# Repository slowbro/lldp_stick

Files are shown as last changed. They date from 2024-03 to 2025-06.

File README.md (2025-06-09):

# LLDP Stick

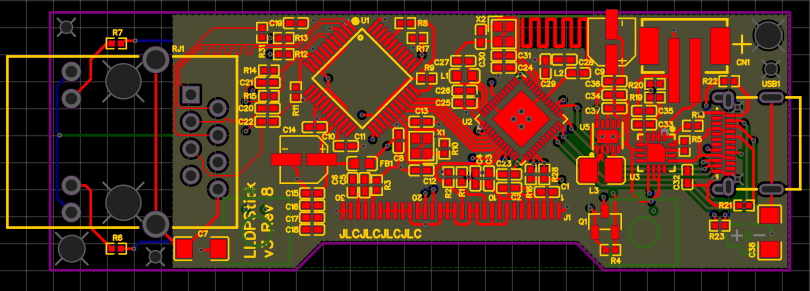
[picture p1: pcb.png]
PCB Image


## What is it?
A network diagnostic tool. Initial goal is to show LLDP information; future goal is to allow more network diagnostics over BLE with a phone app.

## Goals

- [ ] Additional diagnostics via BLE
    - [ ] Set/reset MAC Address
    - [ ] DHCP
    - [ ] Ping
- [ ] Support CDP
- [x] Reduce idle power draw (and thus improve battery life)
    - Rev 0 34mA
    - Rev 2 7mA
    - Rev 3 150uA
    - Rev 7+ 24uA!
- [ ] 1G PHY: Support switches that don't go down to 100M (i.e. Arista DCS-7280TR)
- [ ] Cost reduction: $20-$30 per stick

## Dependencies

Requires `s132_nrf52_2.0.1_softdevice.hex` to be placed in `~/.platformio/packages/framework-arduinonordicnrf5/cores/nRF5/SDK/components/softdevice/s132/hex/`. The binary can be downloaded from Nordic Semi [here](https://www.nordicsemi.com/Products/Development-software/nRF5-SDK/Download) under '11.0.0nRF5 SDK'.

## Building

1. Install [PlatformIO](https://platformio.org/).
2. Clone the repository.
3. See "Dependencies" above - download and copy the SoftDevice hex file to the proper location. You may need to try `pio run` first to download the apporiate libraries.
4. Run platformio: `pio run`.
5. To upload: plug in your J-Link (or other programmer) and run `pio run -t upload`.

## Assembly

You will need:
- The PCB; you can order this from JLCPCB assembled using the included gerber/bom/placement files.
- An 128x64 i2c OLED Display with a SSD1306 controller and FPC connector; I buy from [BuyDisplay](https://www.buydisplay.com/datasheet-128x64-oled-module-spi-0-96-inch-graphic-displays-white-on-black).
- 2x Buttons for the top side: [KSC441JST1LFS at Mouser](https://mou.sr/3FQYgqI) - not available for assembly from JLC.
- RJ45 Jack (if JLC will not assemble it for you) HANRUN [HR911105A at LCSC](https://www.lcsc.com/product-detail/Ethernet-Connectors-Modular-Connectors-RJ45-RJ11_HANRUN-Zhongshan-HanRun-Elec-HR911105A_C12074.html)
- LED chip [XL-2012SURC at LCSC](https://www.lcsc.com/product-detail/LED-Indication-Discrete_XINGLIGHT-XL-2012SURC_C965812.html)
- A small LiPo battery such as DU LITER [902035](https://bihuade.com/products/902035-37v-600mah-liter-energy-battery-polymer-lithium-rechargeable-battery-for-mp3-gps-dvd-bluetooth-recorder-e-book-camera) (600mAh), or DU LITER [802245](https://bihuade.com/products/37v-802245-1000mah-bihuade-lithium-polymer-rechargeable-battery-for-bluetooth-headset-speaker) (1000mAh), with JST PH 2.0mm 2-pin connector.
- The 3D printed case.
- 2x M4x2mm screws.

Steps:
1. [Order your PCBs from JLCPCB](gerber/lldpstick/README.md) (or your manufacturer of choice - the part selection is such that assembly from JLC is turnkey). Continue once PCBs have arrived.
2. (optional) [Order Programmer PCBs from JLCPCB](gerber/programmer/README.md).
3. Solder the OLED FPC connector.
4. Solder buttons onto the front (back?) of the PCB. Also solder the LED if you opted to only have one side of the PCB assembled.
5. Fold the OLED connector over, and superglue the OLED so that the top of the OLED panel is about flush with the top of the PCB.
6. Solder on and lush-trim the RJ-45 connector pins.
7. Program the board with your favorite SWD programmer. I use a J-LINK. This can be done via the exposed pads or the USBC-DAM programmer.
8. 3D print the case - body and one of the lids. Use the development lid if you plan on developing the board, as it will let you hang a SWD connector out the back.
9. Angle the RJ45 side of the board into the case, and then push down on the USB-C end to fit the PCB into the case. Secure with 1-2 M2x4mm screws.
10. Plug in the battery and (ideally) hotglue it in place in the case.
11. Slide the "lid" printed part into its slot on the back of the body of the case.

## Approximate Cost
...assuming you're assembling 5 at a time:

- PCB: $32.50 assembled (assuming top-side-only assembly, DHL shipping, JLCPCB, QTY 5)
- Screen: $3.56
- Battery: $6.40
- Misc components (LED, buttons, screws, case): ~$4

Total: $46.46/ea

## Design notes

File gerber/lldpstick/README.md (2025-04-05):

# LLDP Stick PCB

# How to Order (JLCPCB)

1. Zip all `Gerber_` and `Drill_` files into one zipfile.
2. Upload zipfile to JLCPCB: https://jlcpcb.com/
3. Selection the following options (use defaults if not specified):
    - Surface Finish: LeadFree HASL
    - Confirm Production File: yes
    - Remove Order Number: Specify a Location
4. Select PCB Assemby, using the following options:
    - PCBA Type: Economic
    - Assemby Side: Top
    - Tooling Holes: Added by Customer
    - Confirm Parts Placement: Yes
5. Upload 'BOM_LLDPStick-v3.x.csv' as BOM.
6. Upload 'PickAndPlace_PCB_LLDPStick-v3.x.csv' as CPL.
7. Confirm parts on next page.
    - You may need to replace capacitors/resistors as stock levels tend to shift; make sure you use the same size/capacity!
    - You may need to manually search for and select the RJ45 connector (RJ1) in order to have it placed/assembled.
    - Ignore/"Do Not Place" for the OLED screen.
8. Place your order.

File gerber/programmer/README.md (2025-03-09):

# USBC-DAM Programmer

Use this programmer to expose SWD for programming the LLDPStick. You will need to use a Thunderbolt 3+ cable on the target side - or at the very least, a cable that has all pins connected.

## How to Order (JLCPCB)

1. Zip all `Gerber_` and `Drill_` files into one zipfile.
2. Upload zipfile to JLCPCB: https://jlcpcb.com/
3. Selection the following options (use defaults if not specified):
    - Confirm Production File: yes
4. Select PCB Assemby, using the following options:
    - PCBA Type: Economic
    - Assemby Side: Top
    - Tooling Holes: Added by JLCPCB
    - Confirm Parts Placement: Yes
5. Upload 'BOM_*.csv' as BOM.
6. Upload 'PickAndPlace_*.csv' as CPL.
7. Confirm parts on next page.
    - You may need to replace capacitors/resistors as stock levels tend to shift; make sure you use the same size/capacity!
8. Place your order.

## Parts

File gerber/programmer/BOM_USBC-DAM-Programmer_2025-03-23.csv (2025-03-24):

ID | Name | Designator | Footprint | Quantity | Manufacturer Part | Manufacturer | Supplier | Supplier Part | Price
1 | APT2012LZGCK | D1 | LED-SMD_L2.0-W1.3-R-RD | 1 | APT2012LZGCK | Kingbright | LCSC | C5569446 | 0.37
2 | 1kΩ | R1 | R0805 | 1 | 0805W8F1001T5E | UNI-ROYAL(厚声) | LCSC | C17513 | 0.002
3 | B6B-XH-A(LF)(SN) | U1 | CONN-TH_6P-P2.50_B6B-XH-A-LF-SN | 1 | B6B-XH-A(LF)(SN) | JST | LCSC | C144397 | 0.068
4 | TYPE-C 24P QT | USB1,USB2 | USB-C-SMD_TYPE-C-24P-QT | 2 | TYPE-C 24P QT | SHOU HAN(首韩) | LCSC | C2681555 | 0.465

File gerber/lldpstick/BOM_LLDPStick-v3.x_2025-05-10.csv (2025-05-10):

ID | Name | Designator | Footprint | Quantity | Manufacturer Part | Manufacturer | Supplier | Supplier Part | Price
1 | 4.3kΩ | R5 | R0402 | 1 | RC0402FR-074K3L | YAGEO(国巨) | LCSC | C477725 | 0.001
2 | 1.5kΩ | R23 | R0402 | 1 | RC0402FR-071K5L | YAGEO(国巨) | LCSC | C114759 | 0.001
3 | HR911105A | RJ1 | RJ45-TH_HR911105A | 1 | HR911105A | HANRUN(Zhongshan HanRun Elec) | LCSC | C12074 | 1.444
4 | 4.7uF | C33,C5,C6,C10,C26 | C0402 | 5 | CL05A475MP5NRNC | Samsung Electro-Mechanics | LCSC | C23733 | 0.005
5 | 10kΩ | R18,R1,R2,R4,R8,R9,R16,R17,R28 | R0402 | 9 | 0402WGF1002TCE | UNI-ROYAL(Uniroyal Elec) | LCSC | C25744 | 0.001
6 | BQ24073RGTR | U3 | QFN-16_L3.0-W3.0-P0.50-TL-EP1.7 | 1 | BQ24073RGTR | TI(德州仪器) | LCSC | C15220 | 0.73
7 | 1.5uH | L3 | L1008 | 1 | DFE252012P-1R5M=P2 | muRata(村田) | LCSC | C161084 | 0.143
8 | 10uF | C9,C14 | CAP-SMD_BD4.0-L4.3-W4.3-LS5.0-FD | 2 | RVT1C100M0405 | HONOR(荣誉) | LCSC | C3357 | 0.026
9 | BLM18PG121SN1D | FB1 | L0603 | 1 | BLM18PG121SN1D | muRata(村田) | LCSC | C14709 | 0.007
10 | 10uH | L1 | L0603 | 1 | MCL1608S100MT | Sunlord(顺络) | LCSC | C51942
11 | 330kΩ | R3 | R0402 | 1 | 0402WGF3303TCE | UNI-ROYAL(厚声) | LCSC | C25778 | 0.001
12 | 330Ω | R6,R7 | R0402 | 2 | 0402WGF3300TCE | UNI-ROYAL(厚声) | LCSC | C25104 | 0.001
13 | 1MΩ | R10 | R0402 | 1 | 0402WGF1004TCE | UNI-ROYAL(厚声) | LCSC | C26083 | 0.001
14 | 12.4kΩ | R11 | R0402 | 1 | 0402WGF1242TCE | UNI-ROYAL(厚声) | LCSC | C11692 | 0.001
15 | 49.9Ω | R12,R13,R14,R15 | R0402 | 4 | 0402WGF499JTCE | UNI-ROYAL(Uniroyal Elec) | LCSC | C25120 | 0.001
16 | 806kΩ | R19 | R0402 | 1 | AC0402FR-07806KL | YAGEO(国巨) | LCSC | C227236 | 0.001
17 | 2MΩ | R20 | R0402 | 1 | 0402WGF2004TCE | UNI-ROYAL(Uniroyal Elec) | LCSC | C11512 | 0.001
18 | 5.1kΩ | R21,R22 | R0402 | 2 | 0402WGF5101TCE | UNI-ROYAL(厚声) | LCSC | C25905 | 0.001
19 | 10Ω | R31 | R0402 | 1 | 0402WGF100JTCE | UNI-ROYAL(厚声) | LCSC | C25077 | 0.001
20 | TYPE-C 24P QT | USB1 | USB-C-SMD_TYPE-C-24P-QT | 1 | TYPE-C 24P QT | SHOU HAN(首韩) | LCSC | C2681555 | 0.478
21 | 100nF | C37,C8,C15,C16,C17,C18,C23,C24,C25 | C0402 | 9 | CL05B104KO5NNNC | Samsung Electro-Mechanics | LCSC | C1525 | 0.001
22 | TPS63031DSKR | U5 | SON-10_3X3X05P | 1 | TPS63031DSKR | TI | LCSC | C15516 | 1.12
23 | 1nF | C35 | C0402 | 1 | 0402B102K500NT | FH (Guangdong Fenghua Advanced Tech) | LCSC | C1523 | 0.001
24 | 3.9nH | L2 | L0402 | 1 | SDCL1005C3N9STDF | Sunlord(顺络) | LCSC | C14033
25 | ER-OLED0.96-1W | J1 | 1X30-0.7MM | 1 | BuyDisplay |  |  | https://www.buydisplay.com/datasheet-128x64-oled-module-spi-0-96-inch-graphic-displays-white-on-black
26 | MMBT3906_C2143 | Q1 | SOT-23-3_L2.9-W1.3-P1.90-LS2.4-BR | 1 | MMBT3906 2A | CJ(江苏长电/长晶) | LCSC | C2143 | 0.011
27 | 8pF | C30,C31 | C0402 | 2 | GJM1555C1H8R0BB01D | muRata(村田) | LCSC | C161335 | 0.014
28 | 1uF | C1,C2,C3,C4,C27 | C0402 | 5 | CL05A105KA5NQNC | Samsung Electro-Mechanics | LCSC | C52923 | 0.003
29 | 10nF | C11,C22 | C0402 | 2 | CL05B103KB5NNNC | Samsung Electro-Mechanics | LCSC | C15195 | 0.001
30 | 18pF | C12,C13 | C0402 | 2 | 0402CG180J500NT | FH (Guangdong Fenghua Advanced Tech) | LCSC | C1549 | 0.001
31 | 6.8nF | C20,C21 | C0402 | 2 | 0402B682K500NT | FH(风华) | LCSC | C1542 | 0.001
32 | 0.8pF | C28 | C0402 | 1 | CC0402BRNPO9BNR80 | YAGEO(国巨) | LCSC | C327032 | 0.002
33 | 100pF | C29 | C0402 | 1 | 0402CG101J500NT | FH(风华) | LCSC | C1546 | 0.001
34 | 10uF | C32,C34,C36 | C0402 | 3 | CL05A106MQ5NUNC | SAMSUNG(三星) | LCSC | C15525 | 0.006
35 | 22nF | C19 | C0402 | 1 | 0402B223K500NT | FH (Guangdong Fenghua Advanced Tech) | LCSC | C1532 | 0.002
36 | 32MHz | X2 | CRYSTAL-SMD_4P-L2.0-W1.6-BL | 1 | XL7EL89CKI-111YLC-32M | YXC(扬兴晶振) | LCSC | C2965582 | 0.079
37 | 1nF | C7,C38 | C1206 | 2 | 1206B102K202NT | FH(风华) | LCSC | C9196 | 0.008
38 | B2B-PH-SM4-TB (LF)(SN) | CN1 | CONN-SMD_B2B-PH-SM4-TB-LF-SN | 1 | B2B-PH-SM4-TB(LF)(SN) | JST | LCSC | C160352 | 0.198
39 | W5500 | U1 | LQFP-48_L7.0-W7.0-P0.50-LS9.0-BL | 1 | W5500 | WIZNET | LCSC | C32843 | 3.175
40 | NRF52832-QFAA-R | U2 | QFN-48_L6.0-W6.0-P0.40-BL-EP3.8 | 1 | NRF52832-QFAA-R | NORDIC | LCSC | C77540 | 2.879
41 | 25MHz | X1 | CRYSTAL-SMD_4P-L2.0-W1.6-BL | 1 | 7D025000Q01 | HD(浩都频率) | LCSC | C648942 | 0.108
42 | KSC441JST1LFS | SW1,SW2 | SMD-6.2X6.2X3.5 | 2 | KSC441JST1LFS | C&K | Mouser | 611-KSC441JST1LFS
43 | XL-2012SURC | LED1 | LED0805-R-RD | 1 | XL-2012SURC | XINGLIGHT(成兴光) | LCSC | C965812 | 0.006

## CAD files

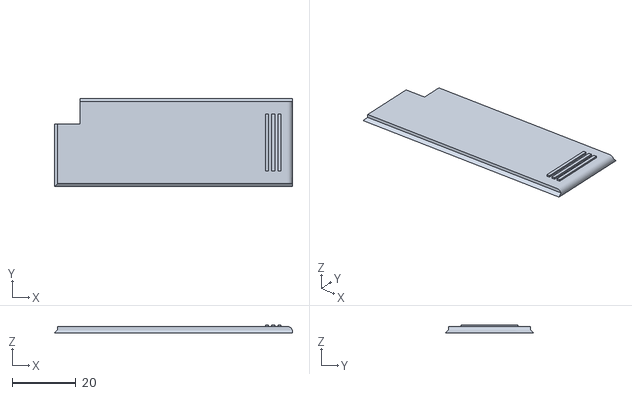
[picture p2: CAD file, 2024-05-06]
case/Development Lid.stl
74.7 x 27.8 x 2.50

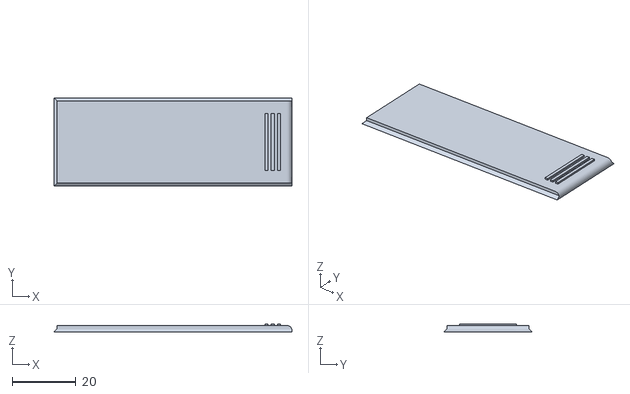
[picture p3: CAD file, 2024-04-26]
case/Lid.stl
74.7 x 27.8 x 2.50

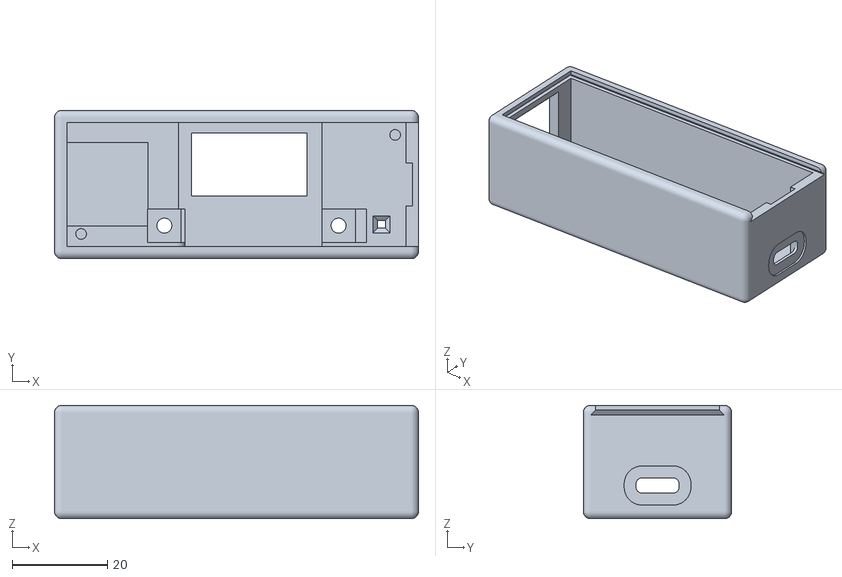
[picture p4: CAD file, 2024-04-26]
case/Body.stl
76.3 x 31.1 x 23.7

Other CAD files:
case/LLDPStick v3 Case.f3d

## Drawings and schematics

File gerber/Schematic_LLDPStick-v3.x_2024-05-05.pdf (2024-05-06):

RJ45 w/ Integrated Magnetics | 3v3 Filters | WizNet W5500

# VDIVLBTN SWDIO

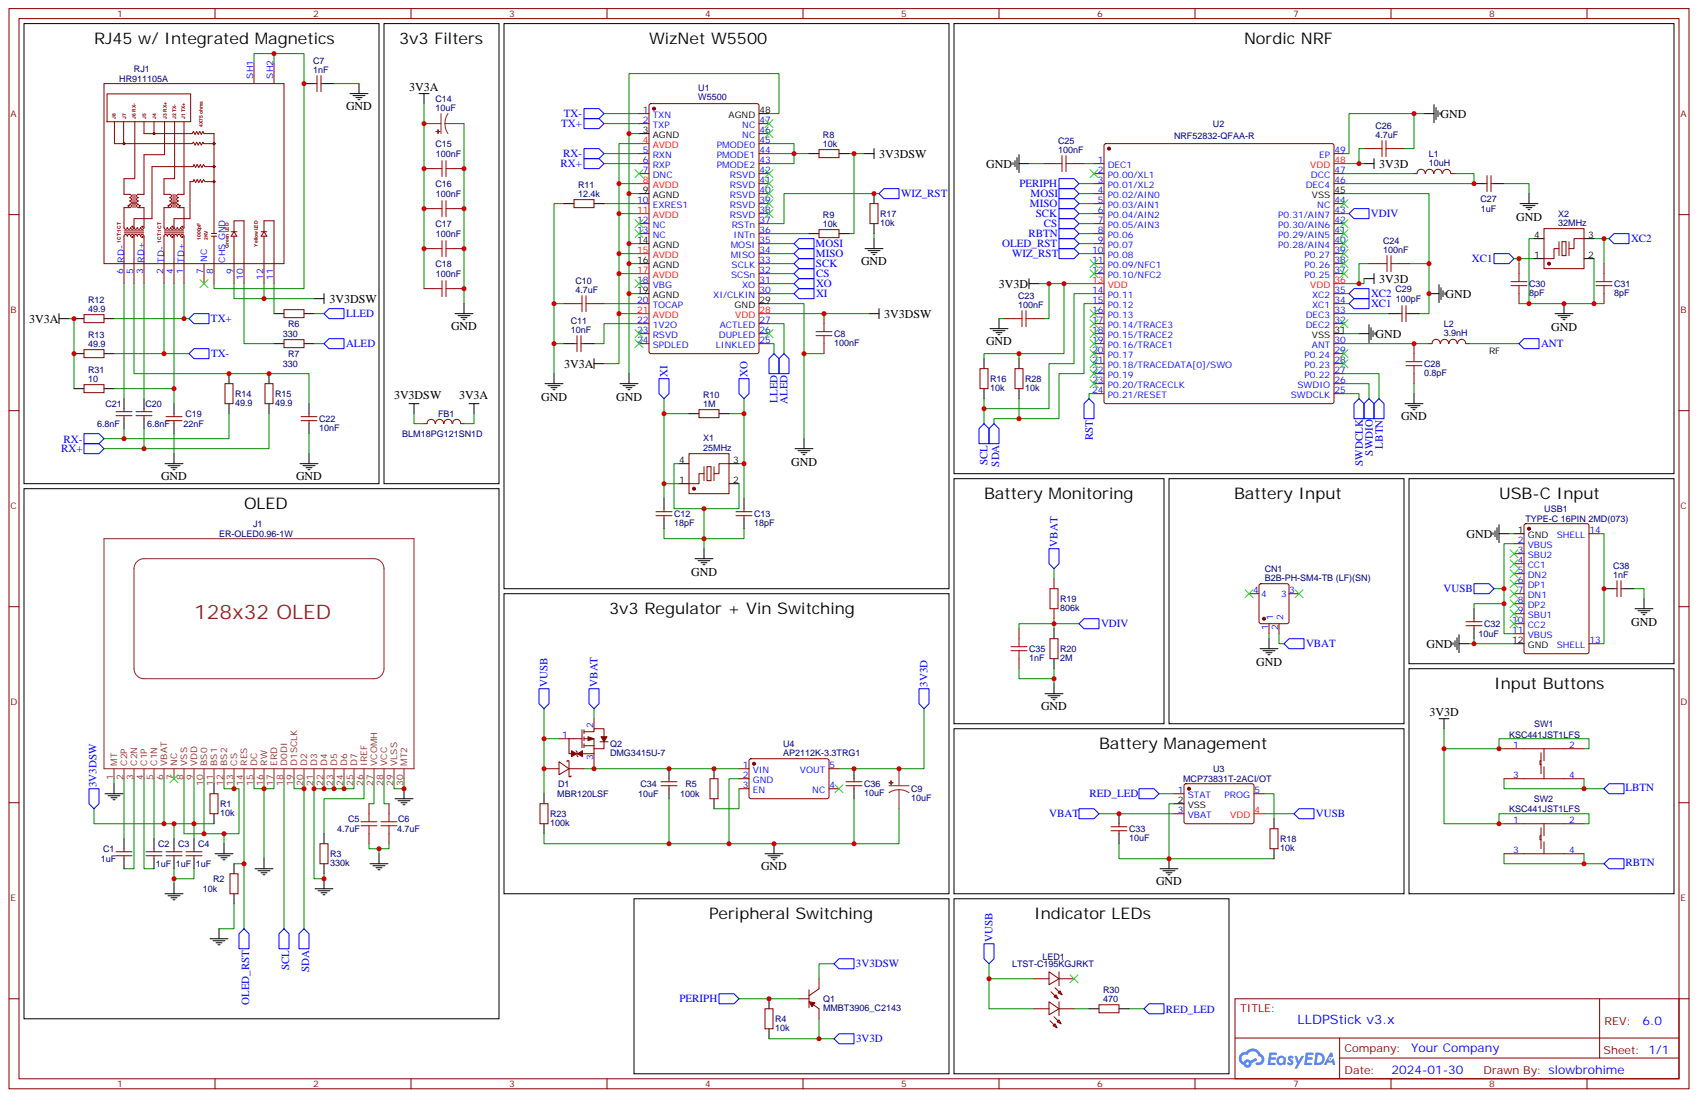
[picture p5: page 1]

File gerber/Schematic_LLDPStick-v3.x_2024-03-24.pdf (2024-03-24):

RJ45 w/ Integrated Magnetics | 3v3 Filters | WizNet W5500

# VDIVLBTN SWDIO

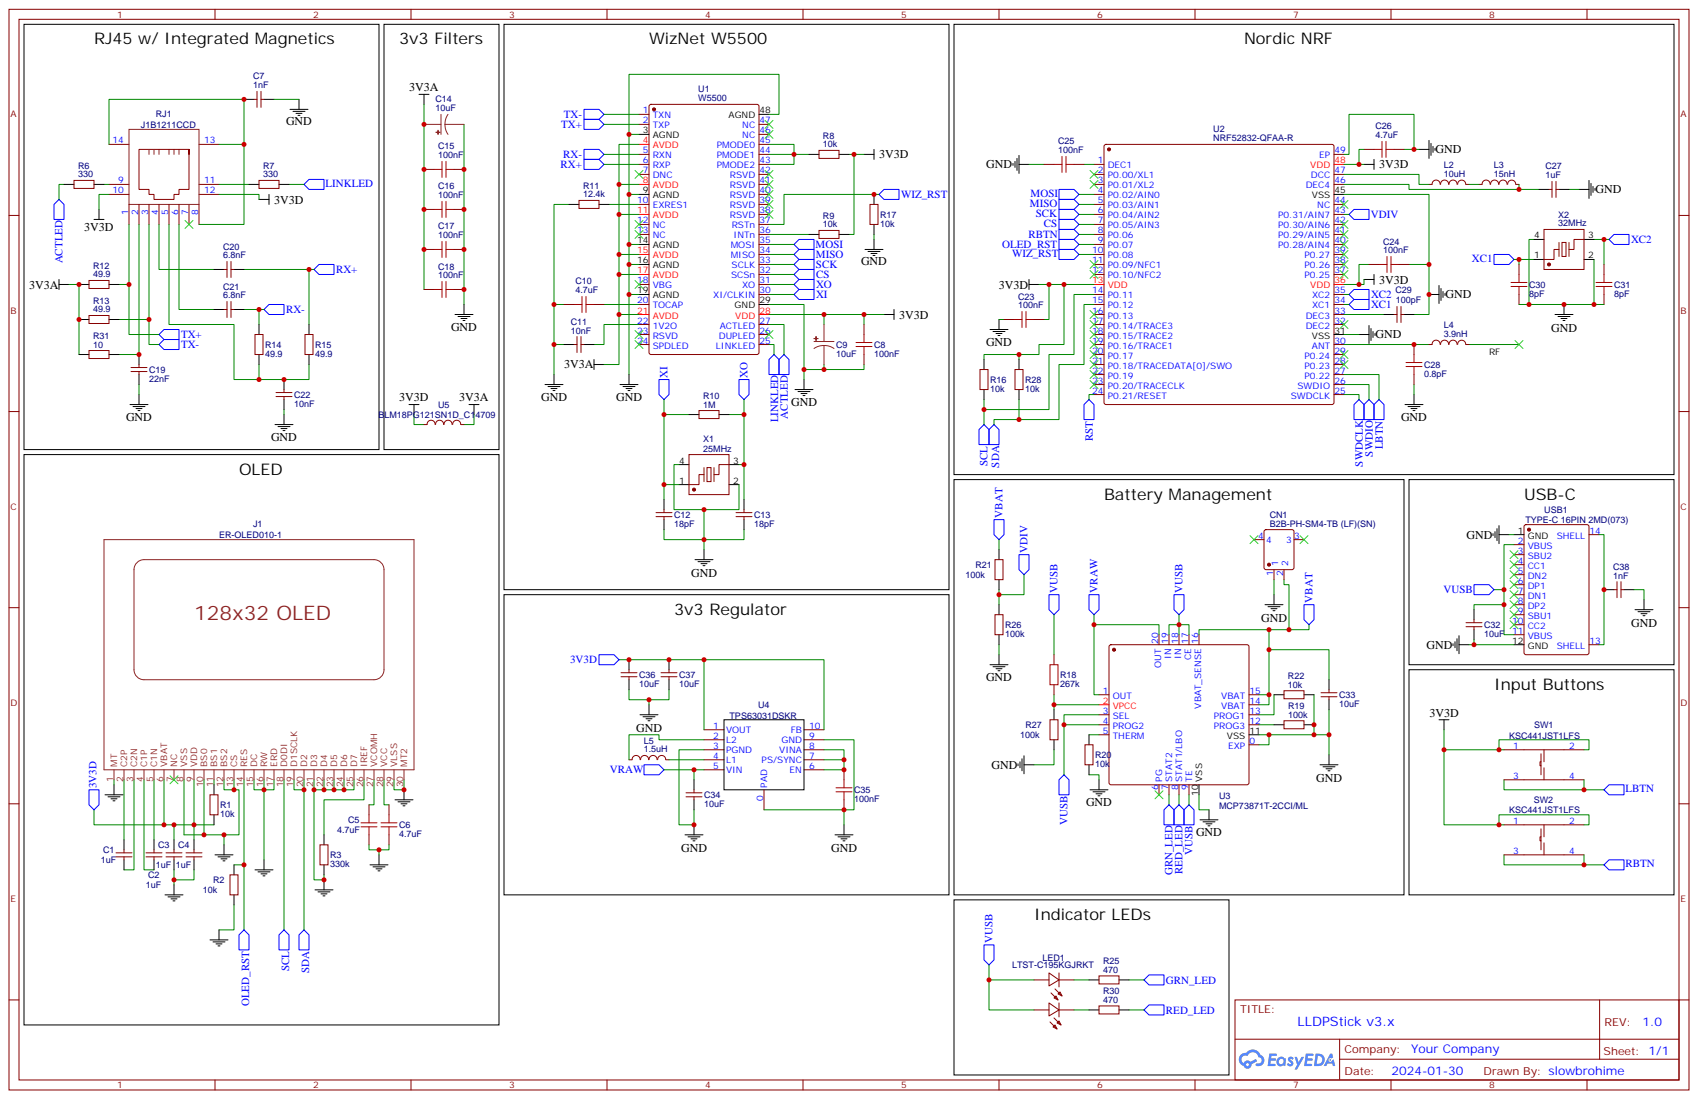
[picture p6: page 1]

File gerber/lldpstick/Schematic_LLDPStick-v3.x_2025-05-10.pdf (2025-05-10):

RJ45 w/ Integrated Magnetics | 3v3a Filters | WizNet W5500

# VDIVLBTN SWDIO

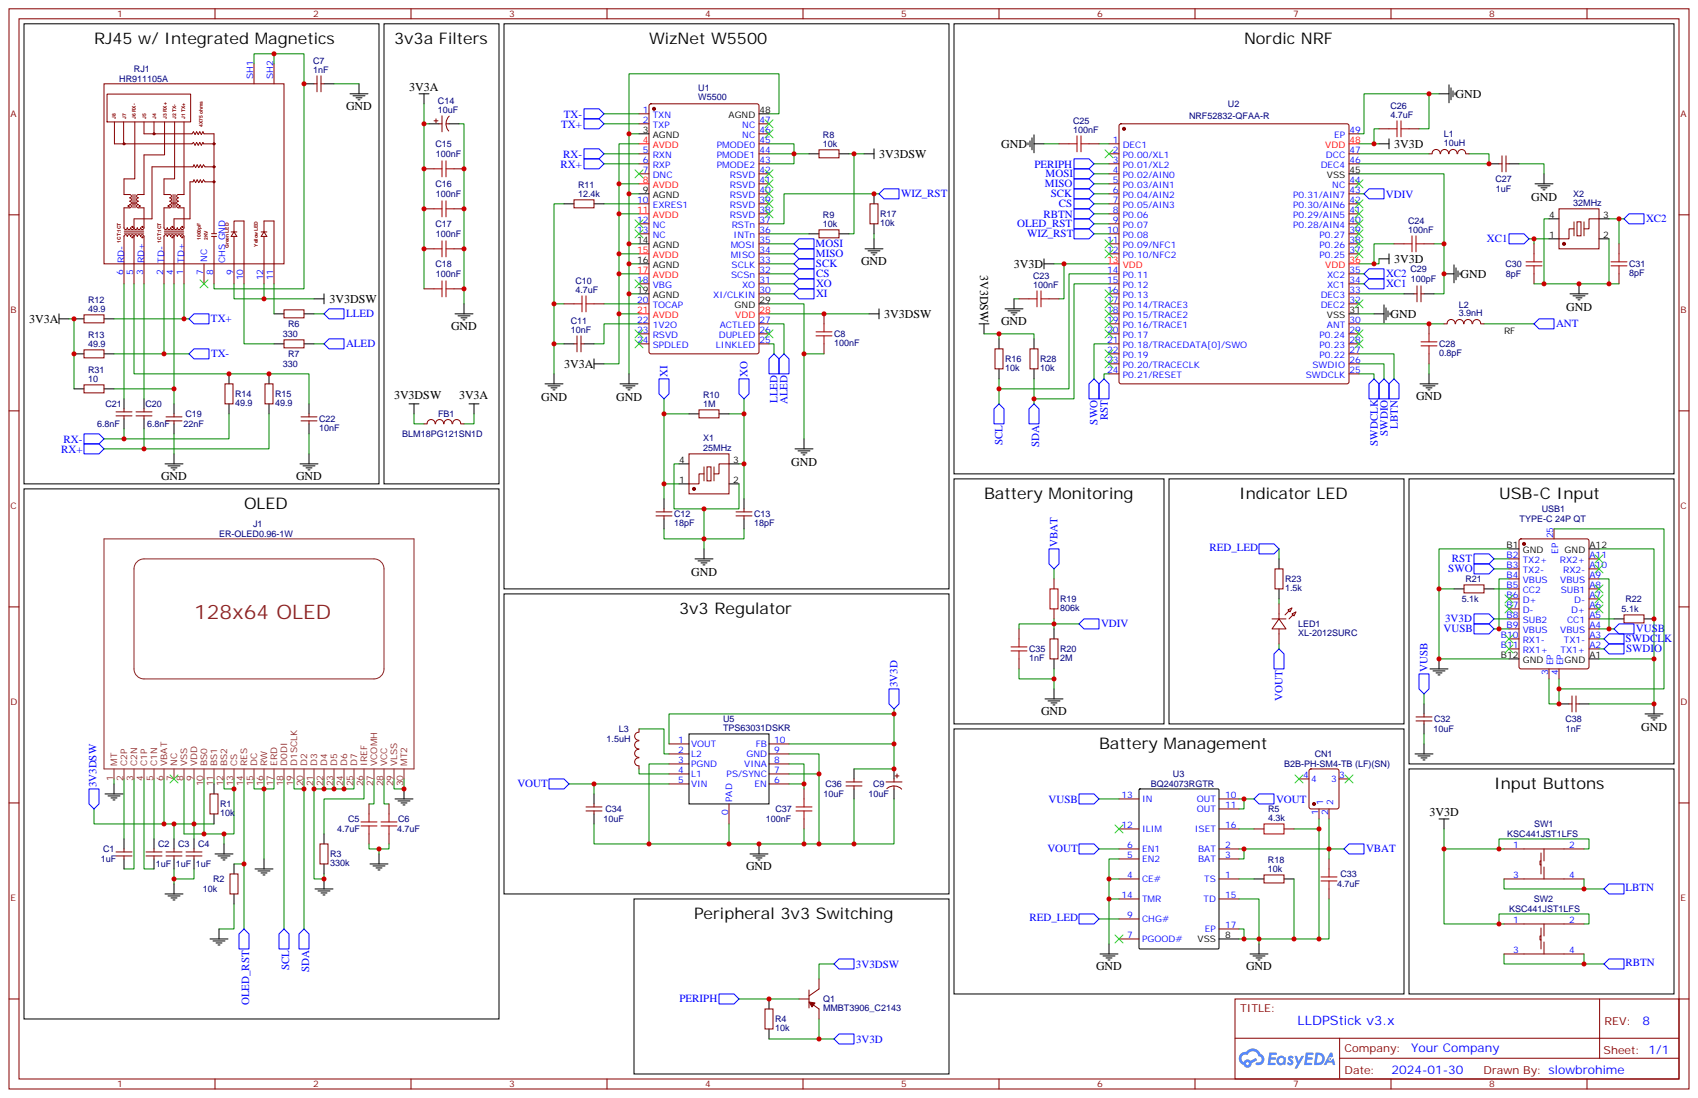
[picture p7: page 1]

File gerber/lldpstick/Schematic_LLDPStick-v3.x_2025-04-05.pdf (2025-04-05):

RJ45 w/ Integrated Magnetics | 3v3a Filters | WizNet W5500

# VDIVLBTN SWDIO

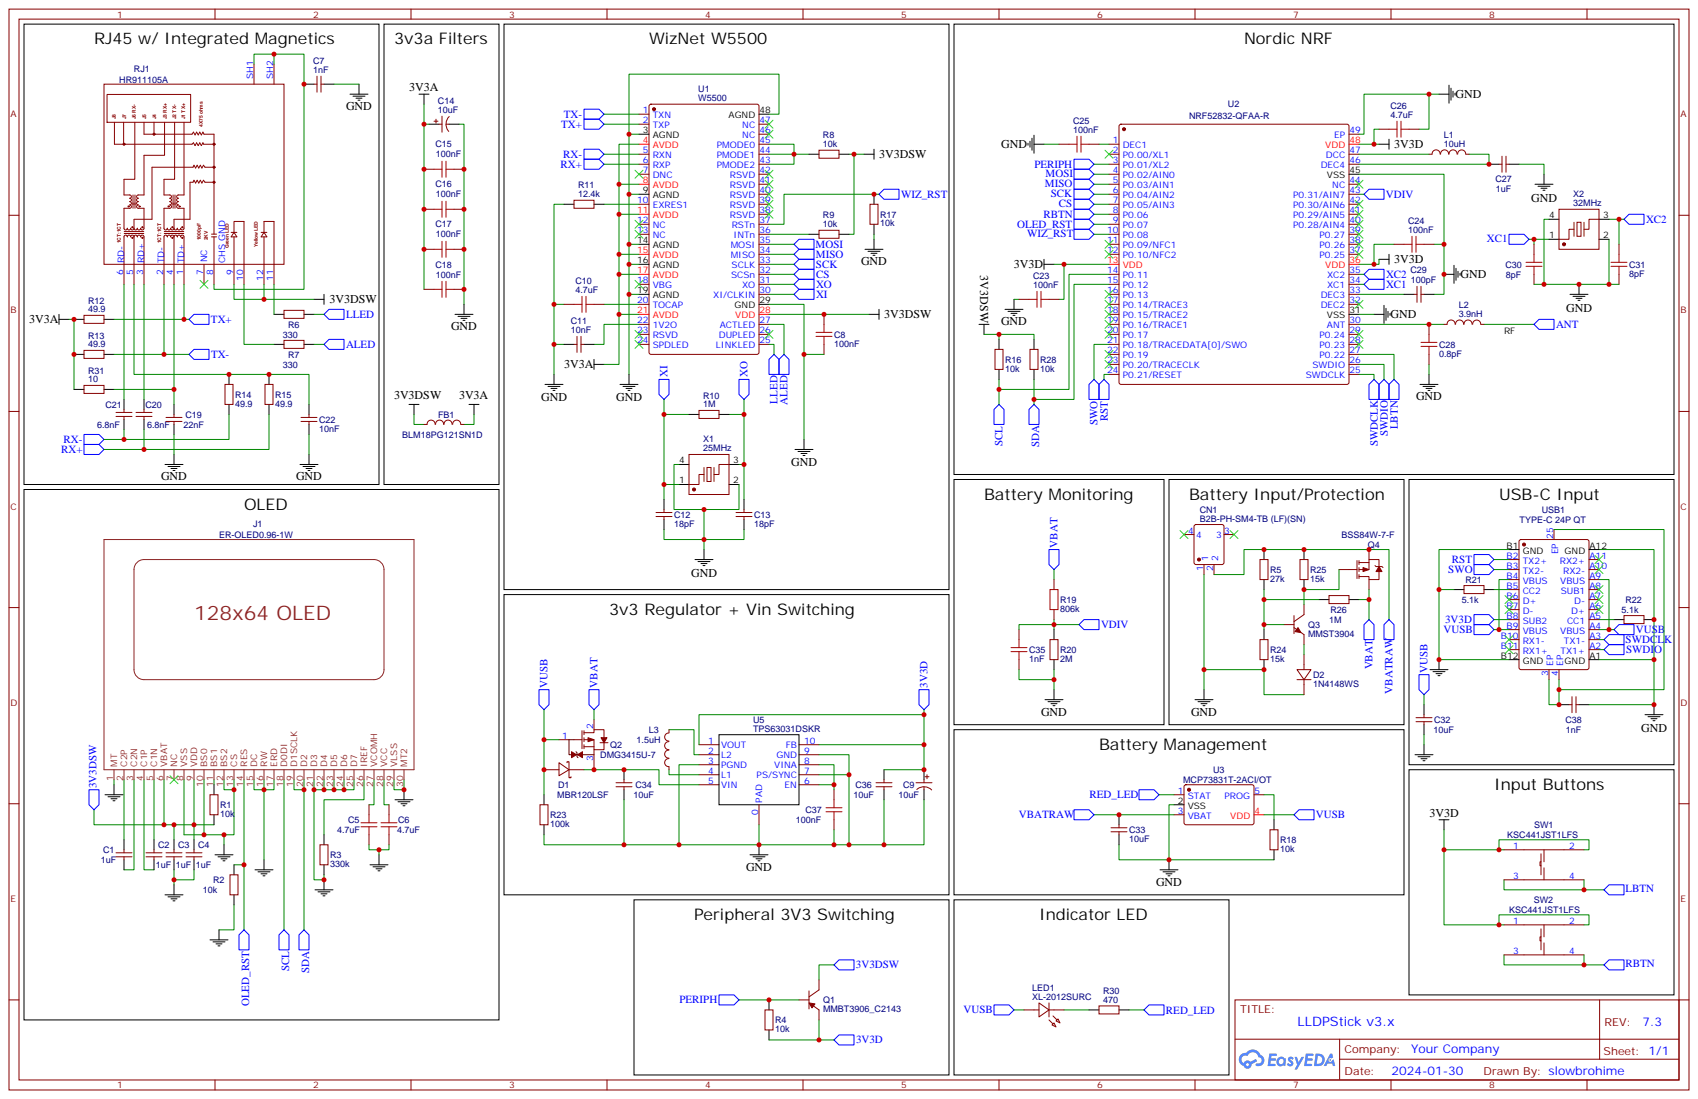
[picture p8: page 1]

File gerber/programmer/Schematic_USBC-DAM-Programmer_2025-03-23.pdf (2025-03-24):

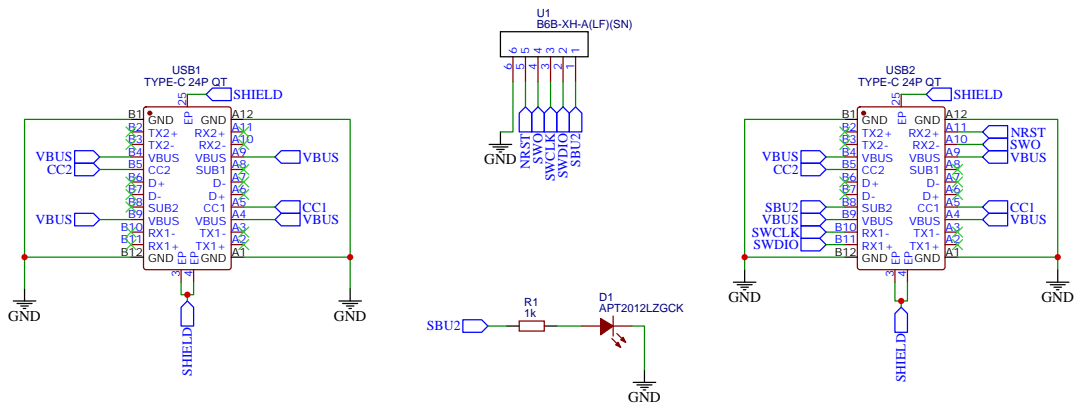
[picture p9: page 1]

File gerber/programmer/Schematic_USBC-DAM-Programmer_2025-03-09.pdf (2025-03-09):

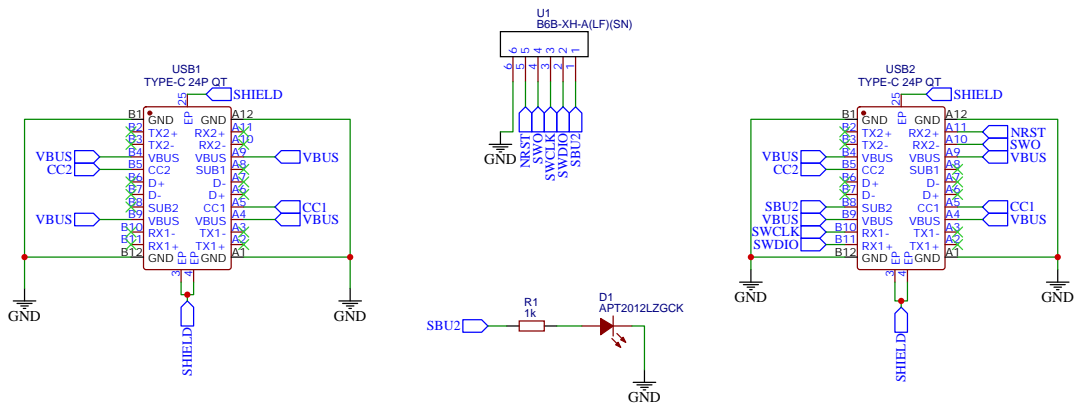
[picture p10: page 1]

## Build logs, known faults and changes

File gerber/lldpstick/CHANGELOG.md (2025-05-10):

# v3 PCB Changelog

## Rev 8
- New battery management IC
- Remove buggy battery protection circuit in favor of said BMIC

## Rev 7.3
- Power I2C pullups from 3V3DSW to save ~150uA of vampire drain in sleep
- Undo the VDIV_EN - it's not going to drain very much and connecting it like that kills the ADC range
- Remove pogopin programming pads
- Add battery protection circuit to cut off VBAT at <3.0v

## Rev 7
- Add support for USB-C DAM (Debug Accessory Mode) - SWD via the USB-C connector! See https://github.com/alvarop/swd2usbc
- switch the gnd for VDIV (VDIV_EN) so as to not waste power when the MCU is asleep
- Update a couple of components that were no longer available through JLCPCB/LCSC: L3, C9, C14
- Replace double-LED package for indicator with single-LED package

## Rev 6
- Switch to cheaper HanRun RJ45 w/ integrated magnetics
- Update battery monitoring voltage divider to add filter/stability capacitor and take advantage of more of the ADC range (thanks Adafruit)
- Add 5.1k resisor to `CC1`/`CC2` lines on USB-C connector to properly negotiate 5V
- Switch back to DC-DC TPS63031 due to high current draw of the LDO setup

## Rev 5
- Much like IPv5, this doesn't really exist

## Rev 4
- Switch to LDO + cheaper battery management chip for cost and energy savings (thanks Adafruit for the design borrowed from [nRF52 Feathers](https://cdn-learn.adafruit.com/assets/assets/000/052/793/original/microcontrollers_revgsch.png?1523067417))
- Re-add inductor for nRF52832 DC-DC Converter
- Remove `SCL`/`SDA` test points

## Rev 3
- Remove superfluous inductor for nRF52832 DC-DC Converter (since the on-board DC-DC prevents us from dipping below 3.3V)
- Power `ACTLED`/`LINKLED` from `3V3DSW`

## Rev 2
- Add `PERIPH` transistor to switch OLED, WizNet on/off
- Remove erroneous resistors on buttons

## Rev 1
- Fix spacing on pogo-pin programming header
- Add test points for `SCL`/`SDA`

## Rev 0
- Initial board

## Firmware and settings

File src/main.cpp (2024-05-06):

#include <Arduino.h>

#include "config.h"
#include "button.h"
#include "lldp.h"
#include "display.h"
#include "menu.h"
#include "sleep.h"
#include "network.h"
#include "battery.h"
#include "ble.h"
#include "setting.h"

void setup(){
    // perform wake/boot actions
    wake();

    // initialize/load settings (before BLE activation)
    setting_init();

    // set up the display
    display_init();

    // set up the buttons
    button_init();

    // initialize the wizchip
    network_init();

    // attach interrupts to both buttons to wake the mcu
    sleep_init_interrupts();

    // read the initial battery voltage
    battery_init();

    // BLE
    ble_init();

    // initialize menu classes
    menu_init();
}

void loop(){
    // autosleep
    sleep_autosleep();

    // do BLE actions
    ble_poll();

    // read the battery voltage
    battery_read();

    // manage buttons
    button_read();

    // display things
    if(menu_active){
        menu.update();

        if(button_lbtn_pressed()){
            menu.lbtn();
        }

        if(button_rbtn_pressed()){
            menu.rbtn();
        }
    } else {
        if(w5500.wizphy_getphylink() == 0){
            got_lldp = false;
            display_clear_buffer();
            display_set_buffer_line_centered(1, "* No Link *");
        } else {
            keep_awake();
            if(!got_lldp) {
                display_clear_buffer();
                display_set_buffer_line(1, "Waiting for LLDP..");
            }

            uint16_t len = w5500.readFrame(network_buffer, sizeof(network_buffer));
            // Ethertype 0x88CC
            if(len > 12 && network_buffer[12] == 136 && network_buffer[13] == 204){
                got_lldp = true;
                PDUInfo pinfo;
                lldp_process(network_buffer, len, &pinfo);

                display_clear_buffer();
                display_set_buffer_line(0, "Switch: ", pinfo.data, pinfo.SystemNameStart, pinfo.SystemNameLength);
                display_set_buffer_line(1, "Port: ", pinfo.data, pinfo.PortIdStart, pinfo.PortIdLength);
                display_set_buffer_line_int(2, "TTL: ", pinfo.data, pinfo.TTLStart, pinfo.TTLLength);
                // optional TLVs
                // this works for now but is kind of undefined behavior
                uint8_t line = 3;
                if(pinfo.PortDescriptionLength != 0){
                    display_set_buffer_line(line, "Desc: ", pinfo.data, pinfo.PortDescriptionStart, pinfo.PortDescriptionLength);
                    line++;
                }
                if(pinfo.SystemNameLength != 0){
                    display_set_buffer_line(line, "SysName: ", pinfo.data, pinfo.SystemNameStart, pinfo.SystemNameLength);
                    line++;
                }
                if(pinfo.SystemDescriptionLength != 0){
                    display_set_buffer_line(line, "SysDesc: ", pinfo.data, pinfo.SystemDescriptionStart, pinfo.SystemDescriptionLength);
                    line++;
                }
                if(pinfo.ManagementAddressLength != 0){
                    display_set_buffer_line(line, "Mgmt: ", pinfo.data, pinfo.ManagementAddressStart, pinfo.ManagementAddressLength);
                    line++;
                }
            }
        }
        display_print();

        if(button_lbtn_pressed()){
            display_buffer_advance();
        }

        if(button_rbtn_pressed()){
            menu_toggle();
        }
    }
}

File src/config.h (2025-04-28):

#ifndef CONFIG_H
#define CONFIG_H

#define OLED_WIDTH 128
#define OLED_HEIGHT 64
#define OLED_LINES 8
#define OLED_MAXLEN 21

#define DISPLAY_LINES OLED_LINES-2
#define DISPLAY_SCROLL_DELAY 250

#define BUTTON_DEBOUNCE_DELAY 50

#define BATTERY_READ_DELAY 1000
#define BATTERY_COEFFICIENT 0.004184

#define SLEEP_AUTOSLEEP_SECONDS 60

#endif

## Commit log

2024-03-24 add gerber files, schematic
    [Drill_NPTH_Through.DRL, Drill_PTH_Through.DRL, Drill_PTH_Through_Via.DRL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]
2024-03-30 fix all the things
    [main.cpp]
2024-04-05 scroll text on display if it's too long
    [config.h]
2024-04-06 update gerber files for rev 2
    [Drill_NPTH_Through.DRL, Drill_PTH_Through.DRL, Drill_PTH_Through_Via.DRL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]
2024-04-08 simplify things while hunting down a memory overflow bug
    [main.cpp]
2024-04-08 fix memory related bug
    [main.cpp]
2024-04-09 battery level display!
2024-04-09 move button logic into its own file(s)
2024-04-11 device info screen, separate network into own files
2024-04-12 break battery shenanigans out, show battery voltage on dev info page
2024-04-12 add 3mf files for initial case
    [Body.3mf, Development Lid.3mf, LLDPStick v3 Case.f3d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]
2024-04-12 cleanup some warnings, cleanup mismatched camel case stuff
2024-04-12 update rev 2 schematic to have a PNP transistor switching the OLED and wizchip power
    [Drill_NPTH_Through.DRL, Drill_PTH_Through.DRL, Drill_PTH_Through_Via.DRL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]
2024-04-12 add assembly instructions/steps to readme
2024-04-12 add BOM and pick n place files for assembly
    [BOM_LLDPStick-v3.x_2024-04-11.csv, PickAndPlace_PCB_LLDPStick-v3.x_2024-04-11.csv]
2024-04-12 update pcb image for rev 2
2024-04-12 export battery voltage via BLE
2024-04-14 fix up displaying only received TLVs
    [main.cpp]
2024-04-17 move PIN definitions to variant
2024-04-17 fix changing the mac address
    [w5500.cpp]
2024-04-20 autosleep timer amount -> settings
2024-04-21 update battery levels for bar display
2024-04-22 don't skip lines when displaying optional TLVs
    [main.cpp]
2024-04-23 update for new board rev
2024-04-26 replace one convoluted menu system with another
    [main.cpp]
2024-04-26 rev 3 idle power: 29.4mW (vs rev 1: 143mW)!
2024-04-26 updated assembly instructions
2024-04-26 replace 3mf with stl
    [Body.3mf, Body.stl, Development Lid.3mf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]
2024-04-26 update gerber files for rev 3
    [BOM_LLDPStick-v3.x_2024-04-11.csv, BOM_LLDPStick-v3.x_2024-04-25.csv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]
2024-04-27 save ~1mA in sleep by disabling the DC-DC converter
2024-04-27 board rev 4
    [BOM_LLDPStick-v3.x_2024-04-25.csv, BOM_LLDPStick-v3.x_2024-04-26.csv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]
2024-04-27 update pcb image
2024-04-28 add link to gerber/README.md
2024-05-04 update readme with new larger battery that fits
2024-05-05 board rev 6: cost savings
    [BOM_LLDPStick-v3.x_2024-04-26.csv, BOM_LLDPStick-v3.x_2024-05-05.csv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]
2024-05-06 PCB changelog
2024-05-06 update rev 6 pcb files
    [BOM_LLDPStick-v3.x_2024-05-05.csv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]
2024-05-06 update development lid for easier cable routing
    [Development Lid.stl]
2024-05-11 update for new rev 6 board
    [BOM_LLDPStick-v3.x_2024-05-05.csv, BOM_LLDPStick-v3.x_2024-05-11.csv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]
2024-05-13 match largest macraw frame size
2024-05-13 fix lldp typo; const for change_mac
    [w5500.cpp]
2024-05-13 switch to SPI.beginTransaction
2025-03-09 update PCB to Rev 7
    [BOM_LLDPStick-v3.x_2024-05-11.csv, BOM_LLDPStick-v3.x_2025-03-08.csv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]
2025-03-09 add VDIV_EN pin (rev 7)
2025-03-09 add programmer gerber files
    [BOM_LLDPStick-v3.x_2025-03-08.csv, BOM_USBC-DAM-Programmer_2025-03-09.csv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]
2025-03-24 update programmer, update to rev 7.3 board
    [BOM_LLDPStick-v3.x_2025-03-08.csv, BOM_LLDPStick-v3.x_2025-03-23.csv, BOM_USBC-DAM-Programmer_2025-03-09.csv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]
2025-03-28 update battery bar ranges
2025-04-05 reduce power draw in sleep to ~24uA by doing some hacky bullshit
2025-04-05 update lldpstick gerber
    [BOM_LLDPStick-v3.x_2025-03-23.csv, BOM_LLDPStick-v3.x_2025-04-05.csv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]
2025-04-05 reduce cost by using JLCPCB Basic parts where possible
    [BOM_LLDPStick-v3.x_2025-04-05.csv]
2025-04-28 update battery coefficient for rev 8, add git rev in device info
2025-05-10 update pcb to rev 8
    [BOM_LLDPStick-v3.x_2025-04-05.csv, BOM_LLDPStick-v3.x_2025-05-10.csv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]
2025-06-09 update link to tactile buttons
